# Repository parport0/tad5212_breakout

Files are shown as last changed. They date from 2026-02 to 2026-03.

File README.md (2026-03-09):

# tad5212_breakout

A breakout board for TI's [TAD5212](https://www.ti.com/product/TAD5212) and [TAD5112](https://www.ti.com/product/TAD5112) DACs (they are drop-in replacements of each other).

Should work as both 2-layer and 4-layer boards. All signals are on layer 1.

If ordering the board with assembly, make sure the orientation of the tantalum caps is correct.

No guarantees on the level of noise, I am inexperienced in PCB design. Raise an issue if you have advice or ideas.

⚠️ I couldn't yet test if headset detection is working or not. The voltage levels on MICDET seem to change (when music is playing and jack detection is turned on via registers), but I could not confirm that the "is headset plugged in?" register value changes — need a kernel driver that allows reading from I2C when it's loaded.

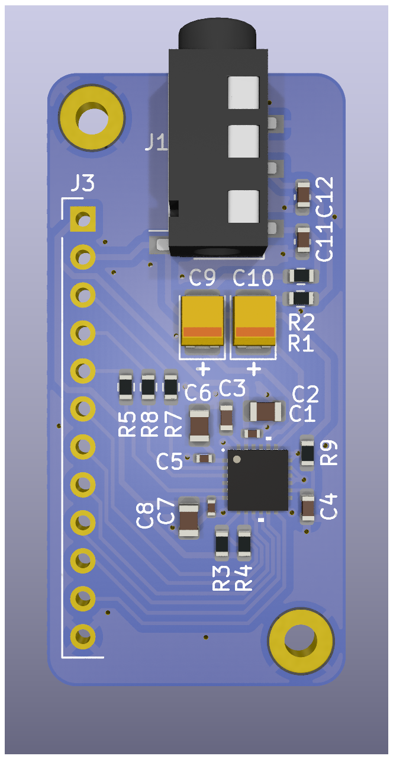
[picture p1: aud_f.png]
Render of the PCB from the front
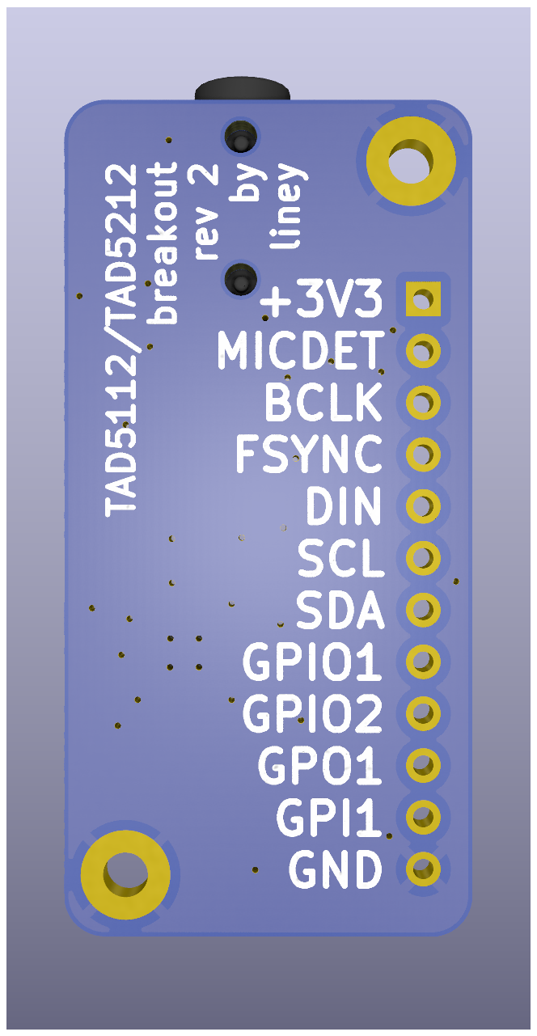
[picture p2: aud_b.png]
Render of the PCB from the back
|  |  |
| --- | --- |

## Usage

I test this board with [PocketBeagle 2](https://docs.beagle.cc/boards/pocketbeagle-2/), kernel 6.18.10, driver snd-soc-pcm6240, and **[this dtso](tad5x12.dtso)**.

Hookup:

| PocketBeagle 2 | Breakout |
| --- | --- |
| P1.26 | SDA |
| P1.28 | SCL |
| P2.01 | BCLK |
| P1.02 | DIN |
| P1.04 | FSYNC |
| P1.14 | +3V3 |
| P1.22 | GND |

My configuration registers ([see binary](tad5212-i2c-2-1dev.bin)):

```
02 01  // DEV_MISC_CFG -- not in sleep
19 40  // 2 data outputs for Primary ASI, no data outputs for Secondary ASI
1a 70  // I2S mode, 32 bits, BCLK and FSYNC polarity standard
64 24  // Stereo single-ended (DAC1A / IN1M -> OUT1P ; DAC1B / IN1P -> OUT1M)
65 60  // OUT1P: headphone driver, 0dB
66 60  // OUT1M: headphone driver, 0dB
67 c9  // Channel 1A: Digital Volume Control set to 0 dB
69 c9  // Channel 1B: Digital Volume Control set to 0 dB
29 30  // TDM is slot 16 or I2S, LJ is right slot 0
76 0c  // CH_EN
78 40  // PWR_CFG
```

## Firmware editing

I do not use the TI tools for firmware editing (TI rejected my requests, likely because I categoried myself as a "hobbyist"), instead I change the firmware by hand.

The firmware is basically a bunch of headers surrounding a set of I2C register addresses and values to write. See [pcm6240.c](https://lwn.net/Articles/961340/).

If using ImHex, this pattern could be convenient to use:

```
#pragma endian big
import std.io;

enum blk_type: u8 {
    PCMDEVICE_BIN_BLK_COEFF = 1,
    PCMDEVICE_BIN_BLK_POST_POWER_UP = 2,
    PCMDEVICE_BIN_BLK_PRE_SHUTDOWN = 3,
    PCMDEVICE_BIN_BLK_PRE_POWER_UP = 4,
    PCMDEVICE_BIN_BLK_POST_SHUTDOWN = 5
};

enum subblk_type: u16 {
    PCMDEVICE_CMD_SING_W = 0x1,
    PCMDEVICE_CMD_BURST = 0x2,
    PCMDEVICE_CMD_DELAY = 0x3,
    PCMDEVICE_CMD_FIELD_W = 0x4,
};

fn format_hex(auto value) {
    return std::format("0x{:02X}", value);
};

struct reg_write_cmd {
    u16 dev_no [[color("888888")]];
    u8 reg [[format("format_hex"), color("FF0000")]];
    u8 value [[format("format_hex"), color("00FF00")]];
};

struct subblk {
    subblk_type subblk_type;
    u16 subblk_len;
    reg_write_cmd cmds[subblk_len];
};

struct data_block {
    u8 dev_idx;
    blk_type block_type;
    u16 yram_checksum;
    u32 block_size;
    u32 n_subblks;
    subblk subblk[n_subblks];
};

u32 file_size @ 0x00;
u32 checksum @ 0x04;
u32 binary_version @ 0x08;
u32 drv_fw_version @ 0x0C;
u8 plat_type @ 0x14;
u8 dev_family @ 0x15;
u8 reserve @ 0x16;

u8 ndev @ 0x17;
u8 devs[0x08] @ 0x18;
u32 nconfig @ 0x20;
u32 config_size[0x40] @ 0x24;

char config_name[0x40] @ 0x124;
u32 nblocks @ 0x164;

data_block data_block[nblocks] @ 0x168;
```

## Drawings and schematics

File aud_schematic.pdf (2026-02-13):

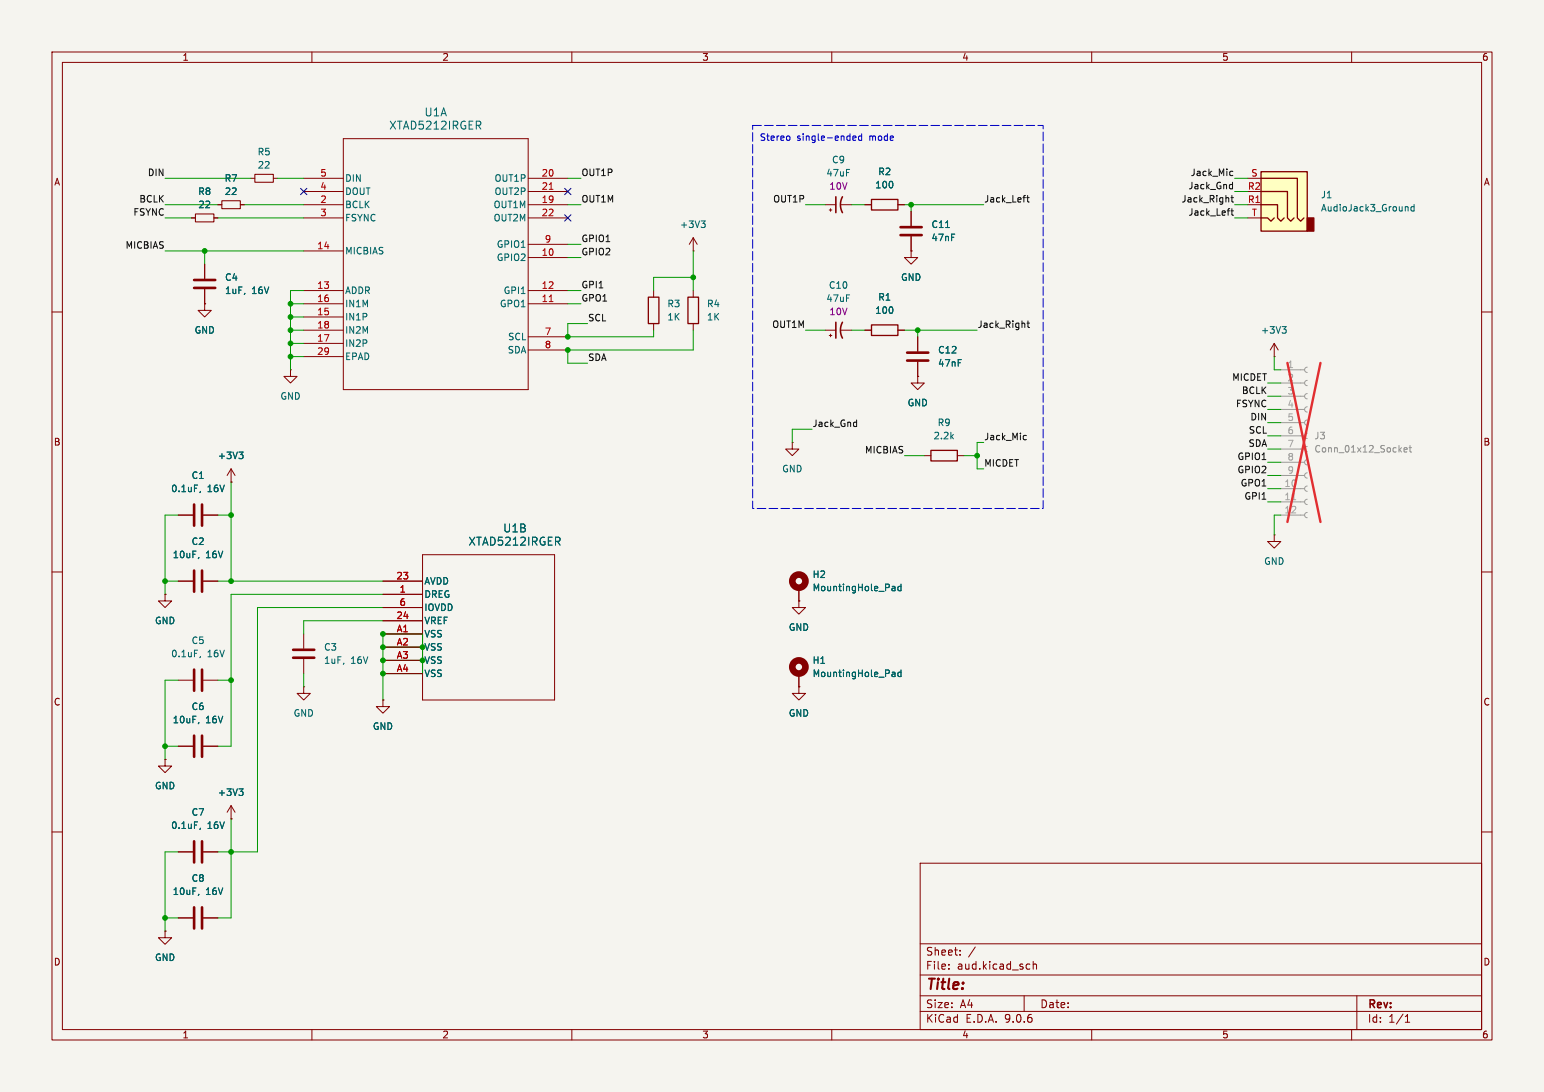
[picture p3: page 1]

Id: 1/1 Title: File: aud.kicad_sch Sheet: /

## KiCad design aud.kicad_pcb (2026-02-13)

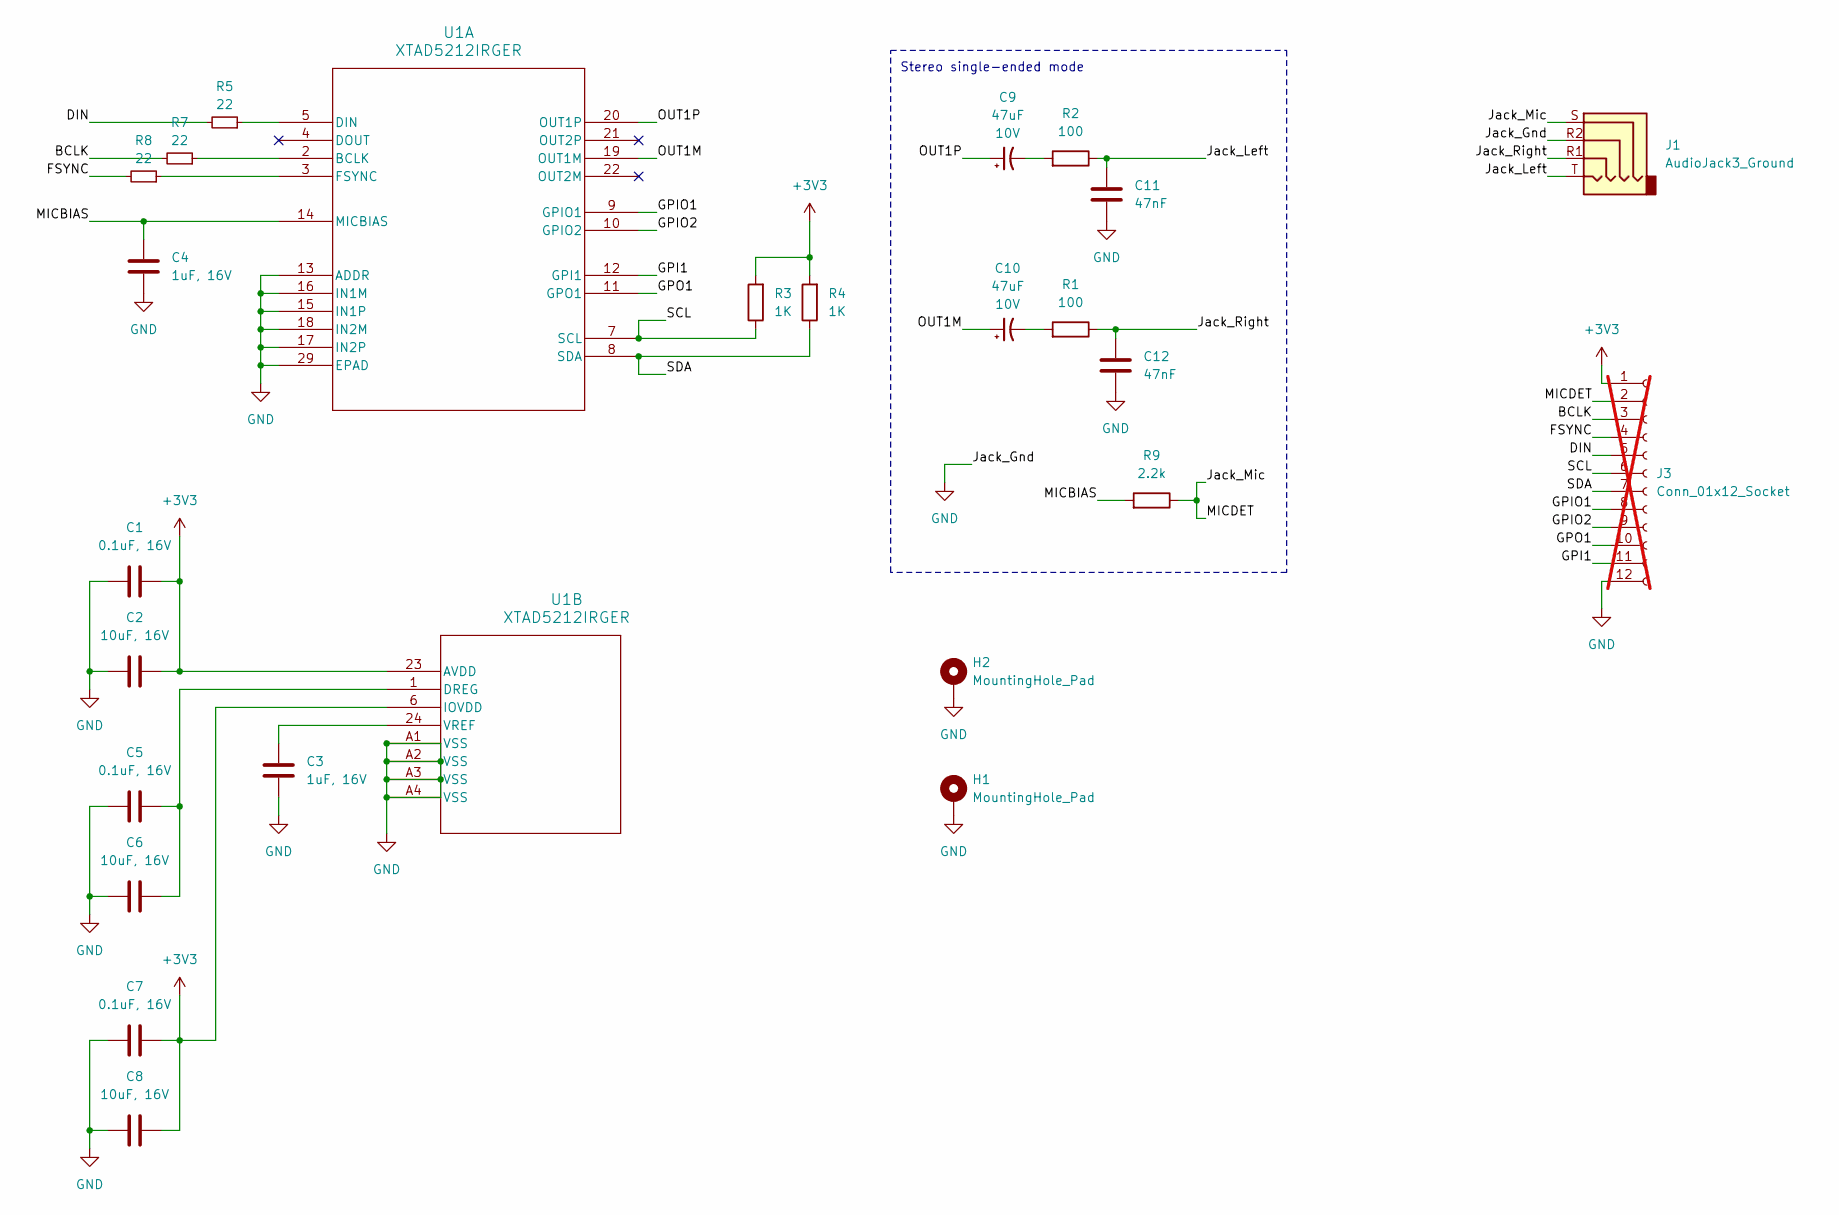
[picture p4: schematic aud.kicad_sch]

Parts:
C1, C5, C7: 0.1uF, 16V; C_0402_1005Metric; LCSC C14663
C2, C6, C8: 10uF, 16V; C_0805_2012Metric; LCSC C96446
C3, C4: 1uF, 16V; C_0603_1608Metric; LCSC C15849
C9, C10: 47uF; CP_EIA-3528-21_Kemet-B; Voltage 10V; LCSC C22036
C11, C12: 47nF; C_0603_1608Metric; LCSC C14663
H1, H2: MountingHole_Pad; MountingHole_2.2mm_M2_Pad
J1: AudioJack3_Ground; Jack_3.5mm_KoreanHropartsElec_PJ-320D-4A_Horizontal; LCSC C95562
J3: Conn_01x12_Socket; PinHeader_1x12_P2.54mm_Vertical; not fitted
R1, R2: 100; R_0603_1608Metric
R3, R4: 1K; R_0603_1608Metric
R5, R7, R8: 22; R_0603_1608Metric
R9: 2.2k; R_0603_1608Metric
U1: XTAD5212IRGER; VQFN24_RGE_CORNERPADS_TEX; LCSC C45068920

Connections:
+3V3: C1.2, C2.2, C7.2, C8.2, J3.1, R3.2, R4.2, U1.6 (IOVDD), U1.23 (AVDD)
/BCLK: J3.3, R7.2
/DIN: J3.5, R5.2
/FSYNC: J3.4, R8.2
/GPI1: J3.11, U1.12 (GPI1)
/GPIO1: J3.8, U1.9 (GPIO1)
/GPIO2: J3.9, U1.10 (GPIO2)
/GPO1: J3.10, U1.11 (GPO1)
/Jack_Left: C11.2, J1.T, R2.1
/Jack_Mic: J1.S, J3.2, R9.1
/Jack_Right: C12.2, J1.R1, R1.1
/MICBIAS: C4.2, R9.2, U1.14 (MICBIAS)
/OUT1M: C10.1, U1.19 (OUT1M)
/OUT1P: C9.1, U1.20 (OUT1P)
/SCL: J3.6, R3.1, U1.7 (SCL)
/SDA: J3.7, R4.1, U1.8 (SDA)
GND: C1.1, C2.1, C3.2, C4.1, C5.1, C6.1, C7.1, C8.1, C11.1, C12.1, H1.1, H2.1, J1.R2, J3.12, U1.13 (ADDR), U1.15 (IN1P), U1.16 (IN1M), U1.17 (IN2P), U1.18 (IN2M), U1.29 (EPAD), U1.A1 (VSS), U1.A2 (VSS), U1.A3 (VSS), U1.A4 (VSS)
unnamed: C9.2, R2.2
unnamed: C10.2, R1.2
unnamed: R7.1, U1.2 (BCLK)
unnamed: R5.1, U1.5 (DIN)
unnamed: R8.1, U1.3 (FSYNC)
unnamed: C5.2, C6.2, U1.1 (DREG)
unnamed: C3.1, U1.24 (VREF)

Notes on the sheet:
Stereo single-ended mode

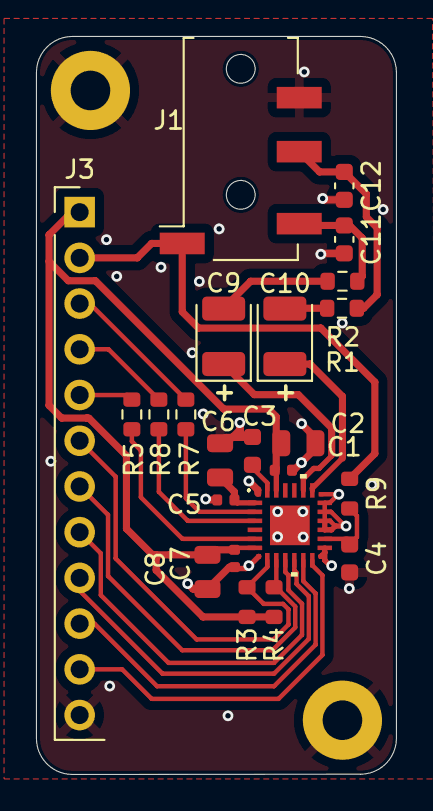
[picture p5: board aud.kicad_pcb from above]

Board: 4 copper layers, 20.0 x 41.0 mm, 25 parts (0 on the bottom side), 24 nets.

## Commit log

2026-01-11 Initial, version 1 import
    [aud.kicad_pcb, aud.kicad_sch]
2026-02-13 Update to version 2
    * Fixes the main mistake of not adding AC coupling caps.
    * Adds a possibly working MICDET pin.
    * Does not break out DOUT anymore.
    [aud.kicad_pcb, aud.kicad_sch]
